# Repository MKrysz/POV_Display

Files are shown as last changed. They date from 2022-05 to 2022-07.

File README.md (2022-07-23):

# Persistance Of Vision Display

## About

Human eye cannot process more than 12 images per second. So by turning on and off moving LEDs it is possible to create an illusion of a stationary image. The goal of this project is to develop a display utilizing this principle. Main modes of the display are going to be: analog and digital clock, showing images and playing videos.

hello world (https://www.youtube.com/watch?v=nO5H2S38heM)
analog clock (https://www.youtube.com/watch?v=prxCtZcyvlo)

## Electronics

As the main purpose of this display is to have a fancy wall clock, one of the main concerns in electronics design was power usage. That's why I decided to use STM32L051C8 as the main MCU, due to its low power usage, high computational capabilities and my familiarity with STM's HAL interface. Power supply consists of Li-Po battery and 2.5V low dropout voltage regulator. Charging battery is done via micro-USB port with TP4056 IC. For driving LEDs I chose a combination of classical 74HC595 8-bit SIPO registers and current limiting resistors. Photodiode is used for calculating rotation time.

Using the KiCad software I came up with following schematic:
Schematic

And PCB design:
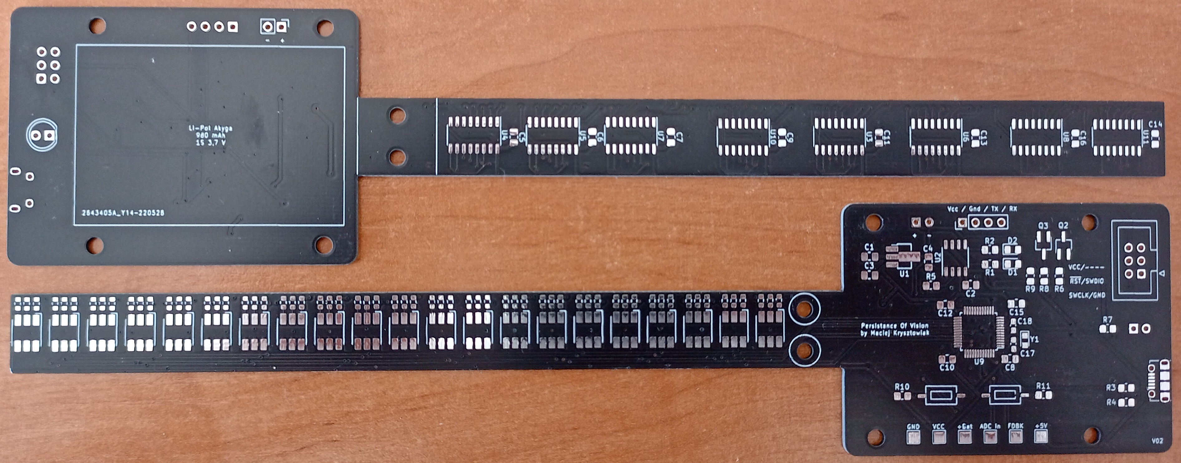
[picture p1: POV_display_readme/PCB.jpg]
PCB


Board after assembling:
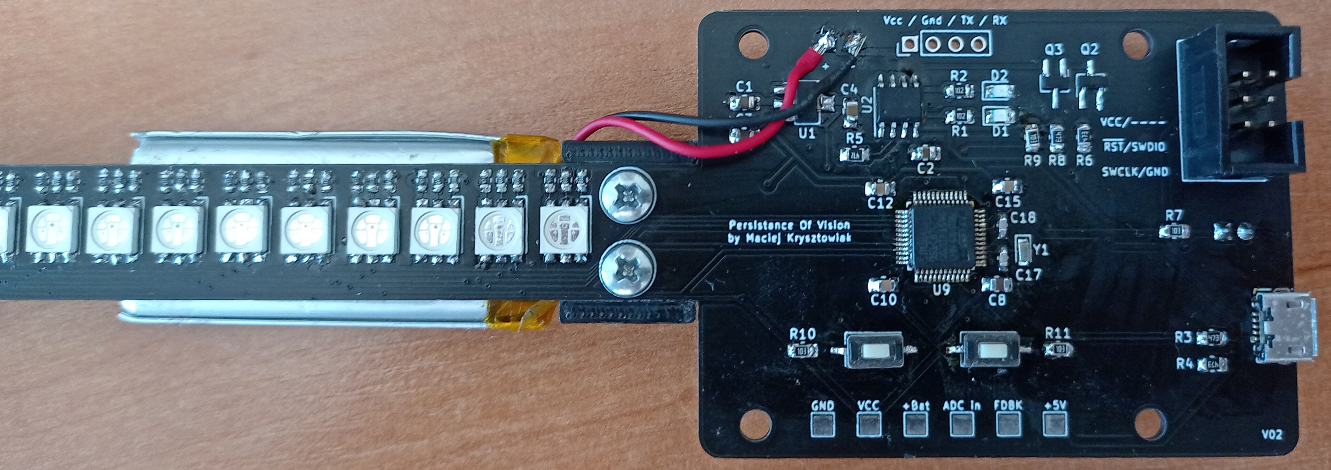
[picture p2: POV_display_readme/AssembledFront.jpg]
Assembled Front

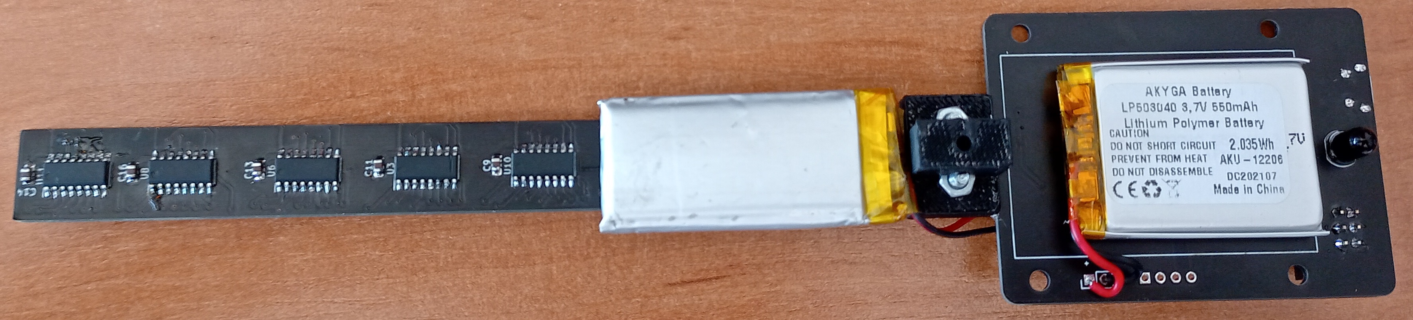
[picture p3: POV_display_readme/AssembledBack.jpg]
Assembled Back


After I glued the main battery in the board wasn't balanced and after trying few methods, I stuck with adding 2nd battery for increased battery life in addition to balancing the PCB.

## MECHANICS

Rotor holder used for connecting the PCB to rotor using two pairs of M3 nuts and bolts.
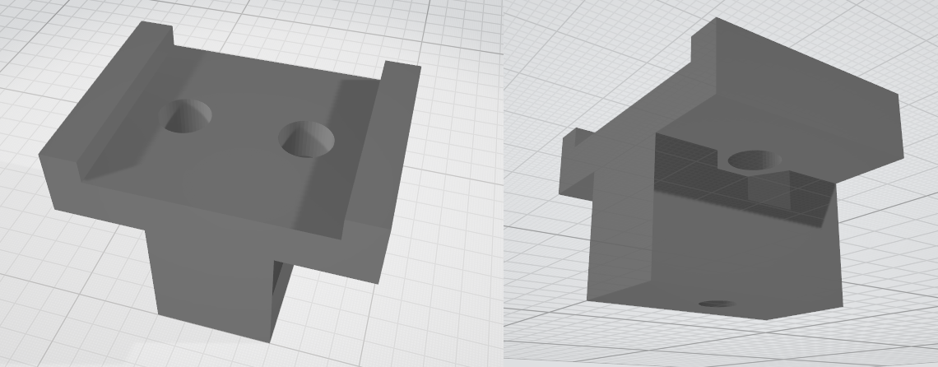
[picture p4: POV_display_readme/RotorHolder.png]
Rotor holder


Motor hodler was printed in 3 separate part because my 3D printer was too small. Parts are mounted together using M3 and M4 nuts and bolts. Motor holder also embeds IR LED.
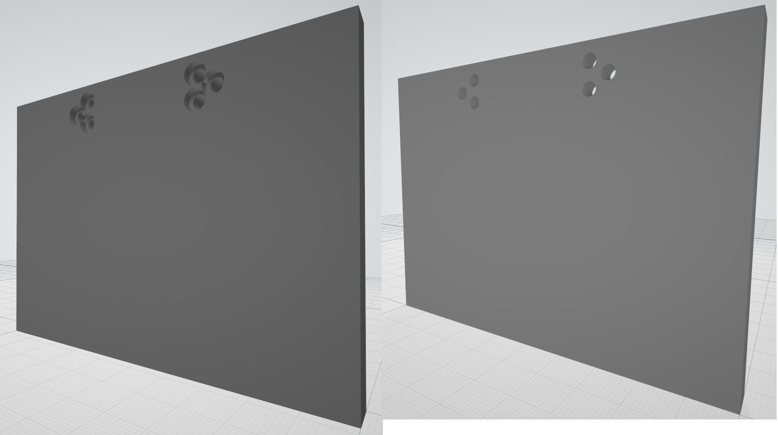
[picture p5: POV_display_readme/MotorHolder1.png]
Motor holder part1

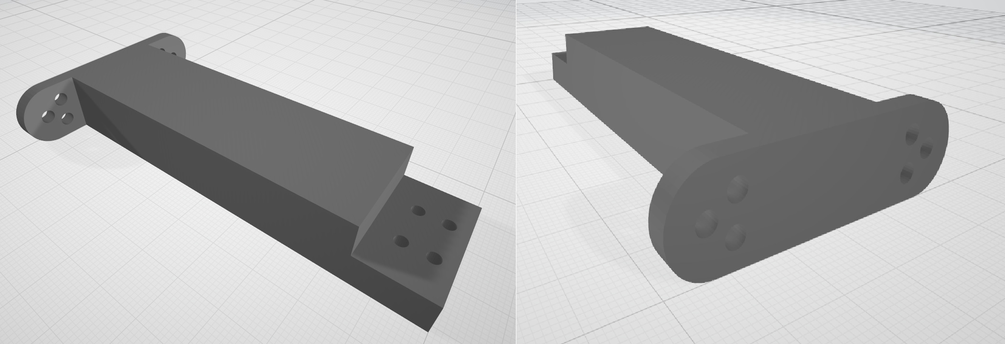
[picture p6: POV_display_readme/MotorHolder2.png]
Motor holder part2

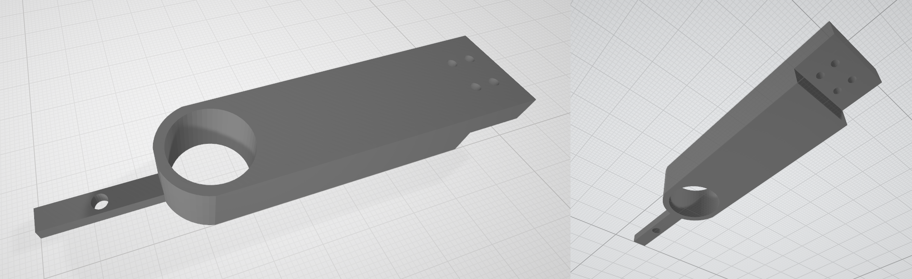
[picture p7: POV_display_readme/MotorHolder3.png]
Motor holder part3


All parts were printed with ABS material.

## SOFTWARE

### IMAGE COMPILER

Python script used for coverting images into a C-style array, that could be programmed into the MCU.

### Embedded

Project was made in VSCode using [stm32-for-vscode](https://www.st.com/en/development-tools/stm32cubemx.html) extension. For this project I used [stm32CubeMX](https://github.com/bmd-studio/stm32-for-vscode) for generating initialization. There are 2 main modes that the display can work in:

- Analog Clock - Mimics classical analog clock
- Image - Displays stationary images, precompiled with python script

Modes and parameters can be chosen via *config.h* file.

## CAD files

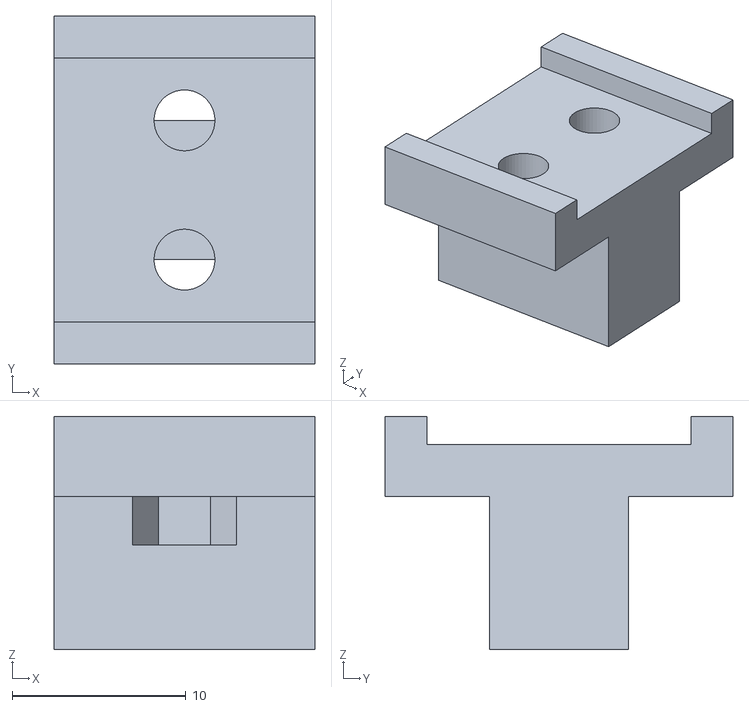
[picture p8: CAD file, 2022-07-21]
POV_display_models/RotorHolder.stl
15.0 x 20.0 x 13.4

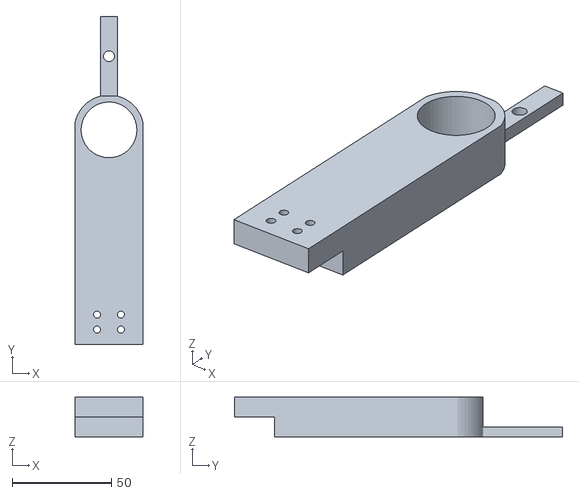
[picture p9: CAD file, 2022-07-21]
POV_display_models/MotorHolder3.stl
34.0 x 164.9 x 20.0

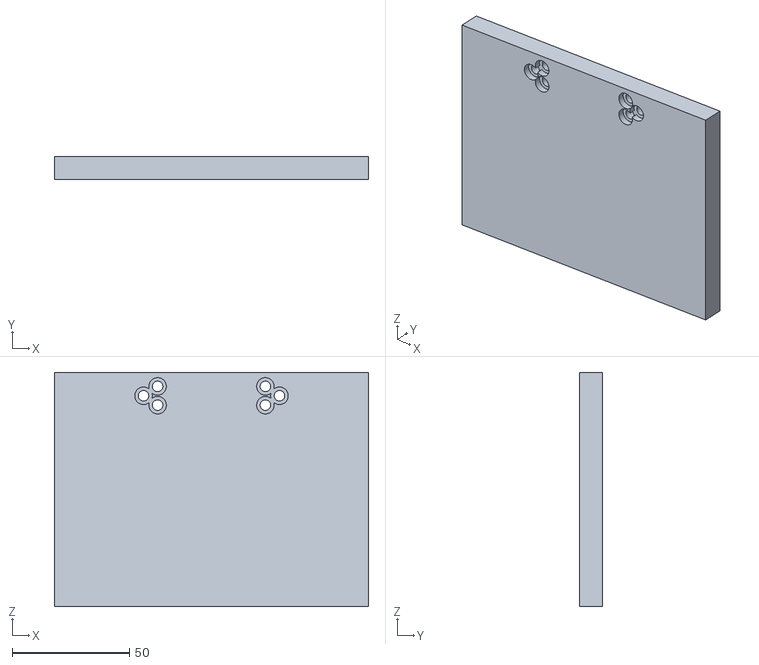
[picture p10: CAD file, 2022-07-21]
POV_display_models/MotorHolder1.stl
134.0 x 10.0 x 100.0

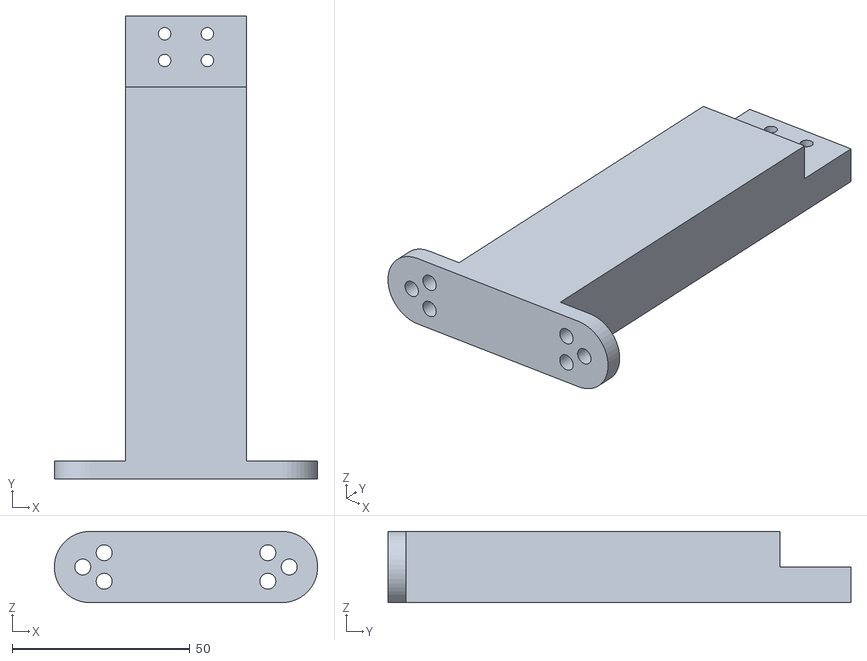
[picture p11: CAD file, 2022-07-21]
POV_display_models/MotorHolder2.stl
74.0 x 130.1 x 20.0

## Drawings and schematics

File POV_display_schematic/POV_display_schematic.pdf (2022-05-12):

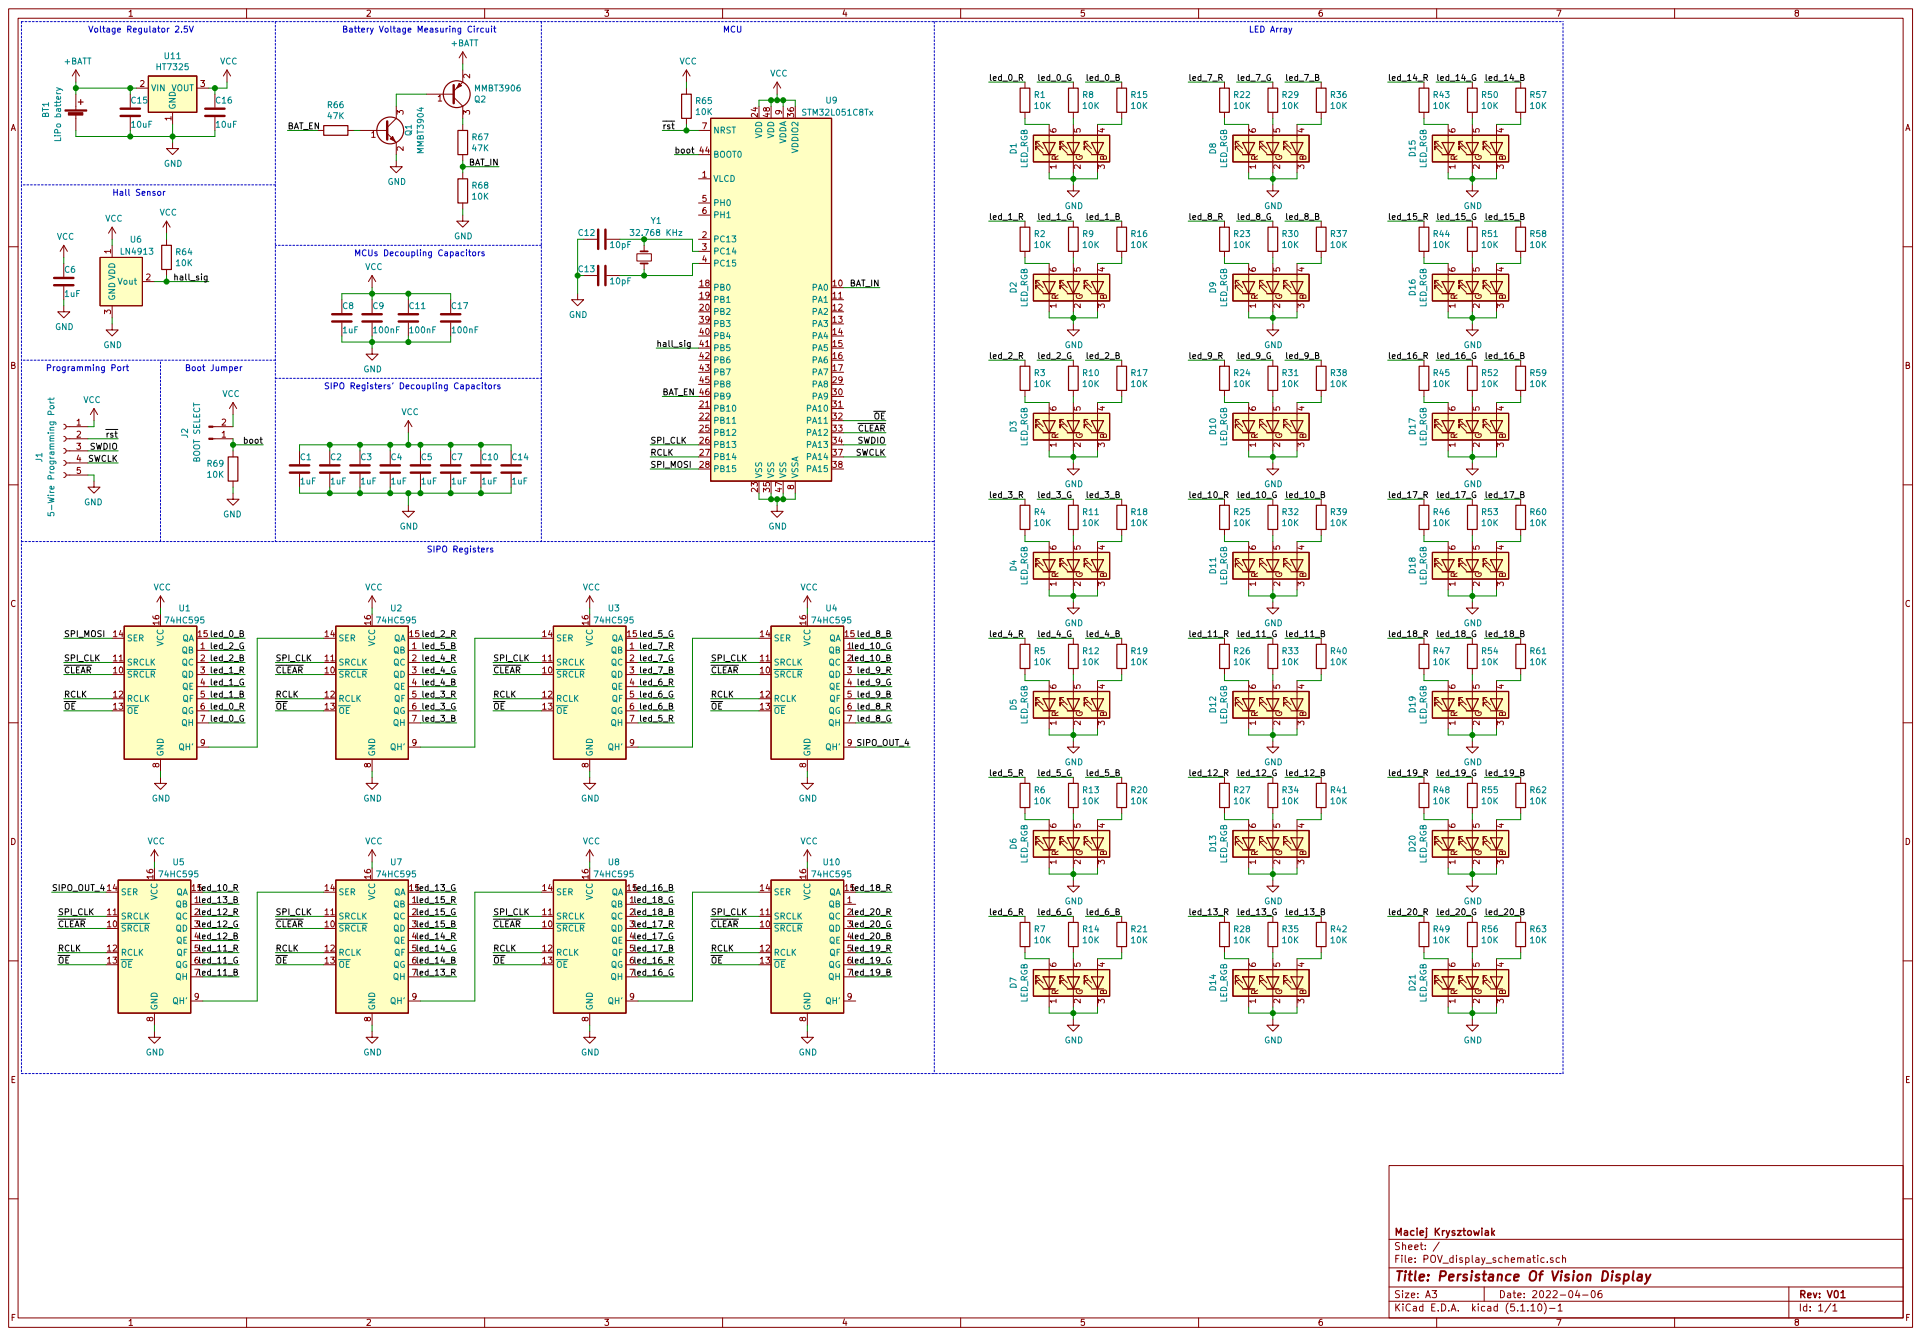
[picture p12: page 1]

4 D1 LED_RGB BT1 LiPo battery GND GND

9 VDDIO2 36 VLCD 1 VSS 23 VSS 35 VSS 47 VSSA

SIPO Registers' Decoupling Capacitors

led_12_R | led_15_G
led_12_G | led_15_B

led_11_R | led_14_G
led_11_G | led_14_B

File: POV_display_schematic.sch Sheet: / Maciej Krysztowiak

Id: 1/1 Title: Persistance Of Vision Display

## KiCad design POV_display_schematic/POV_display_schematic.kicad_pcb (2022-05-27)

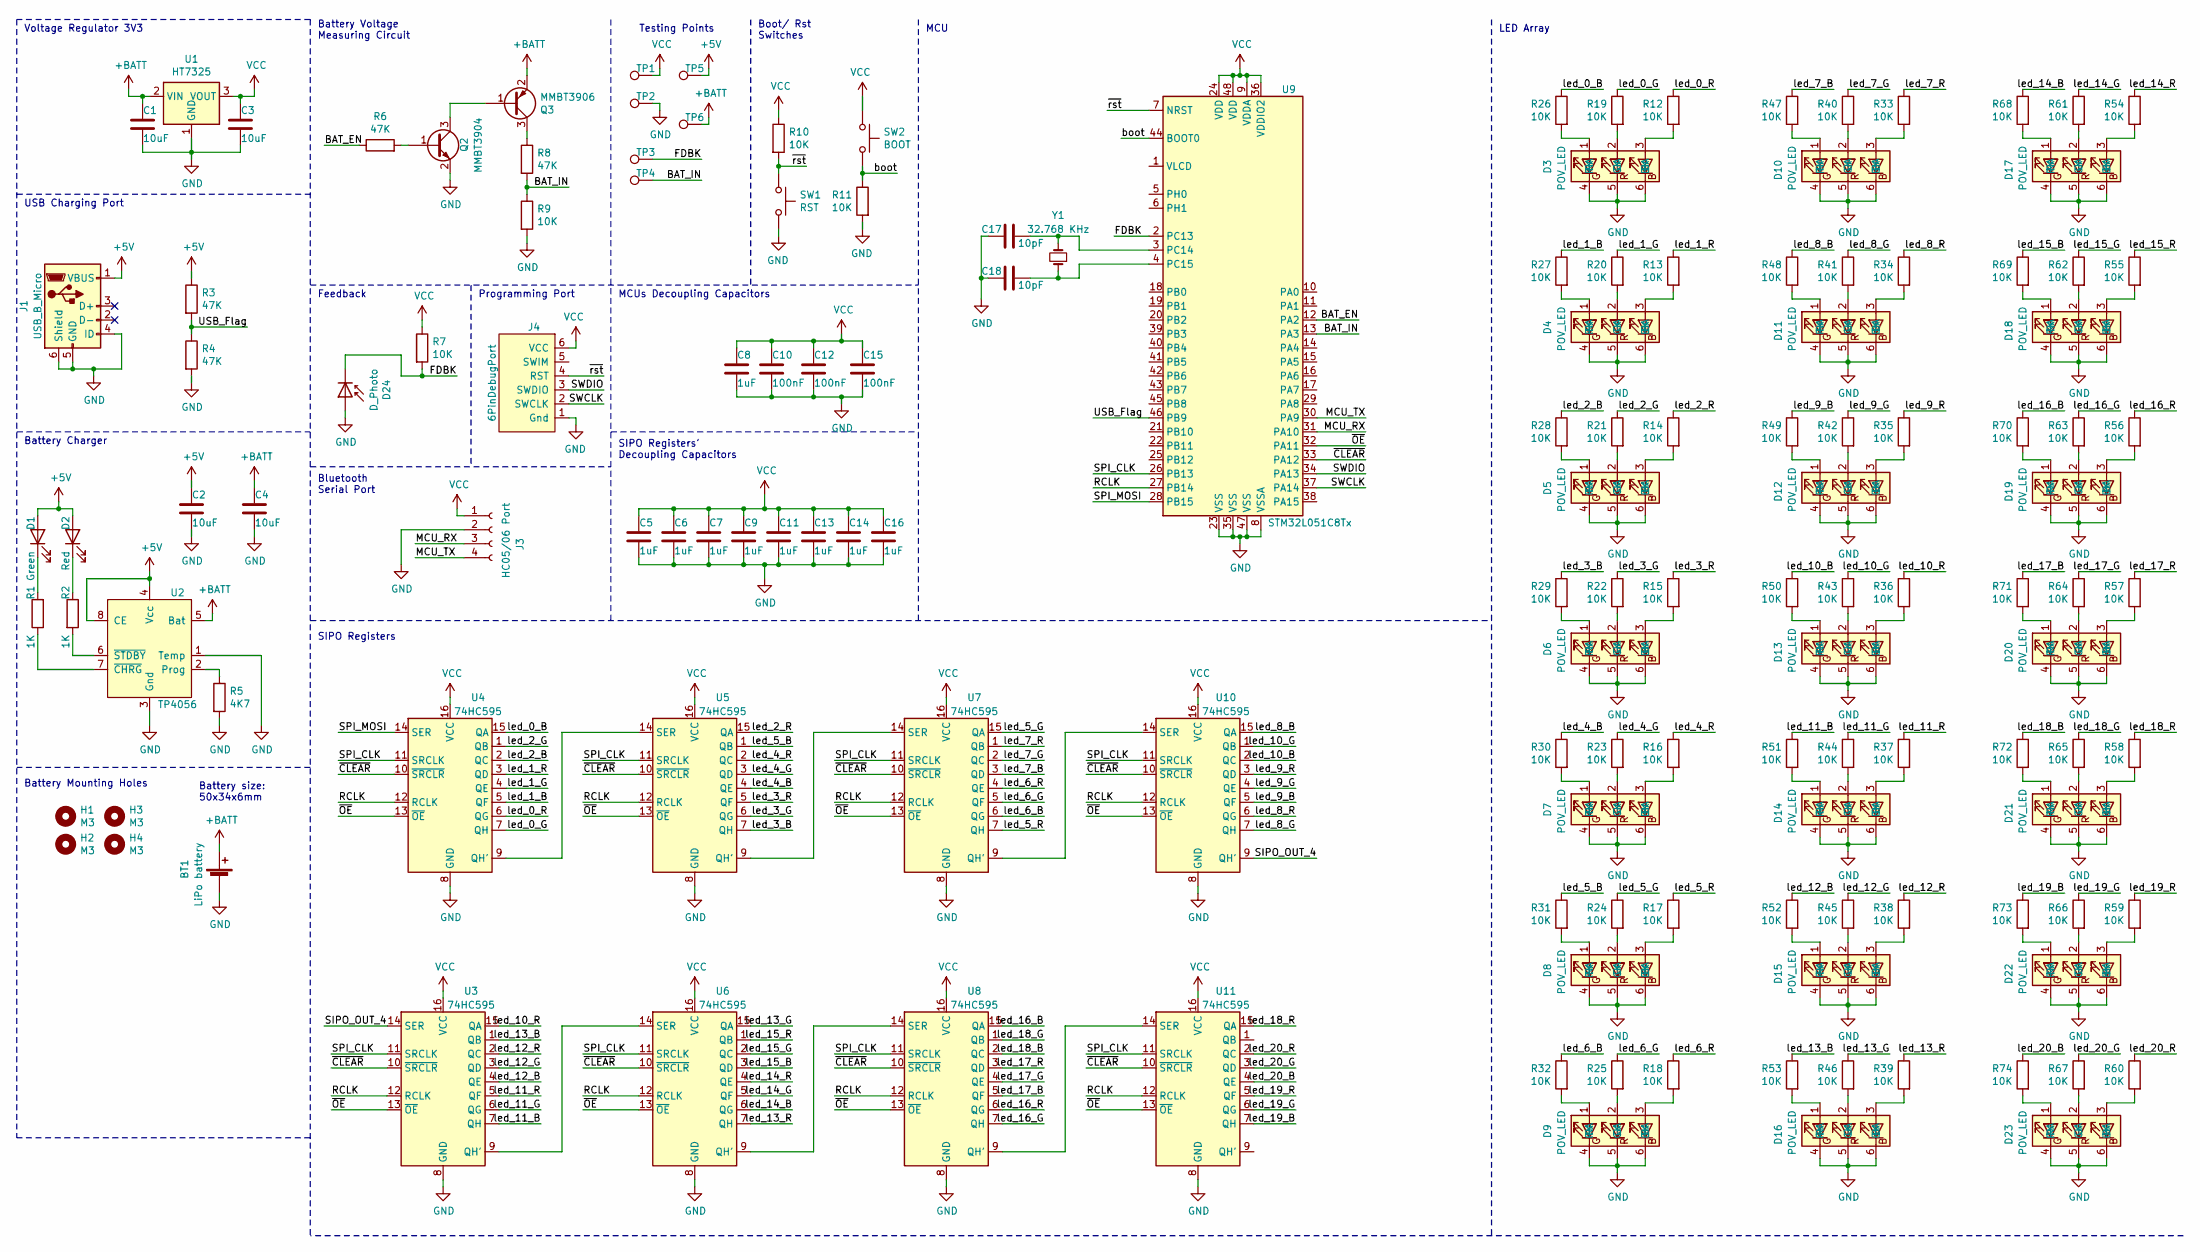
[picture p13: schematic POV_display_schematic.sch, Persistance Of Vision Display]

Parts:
BT1: LiPo battery; PinHeader_1x02_P2.54mm_Vertical
C1, C2, C3, C4: 10uF; C_0805_2012Metric_Pad1.18x1.45mm_HandSolder
C5, C6, C7, C8, C9, C11, C13, C14, C16: 1uF; C_0805_2012Metric_Pad1.18x1.45mm_HandSolder
C10, C12, C15: 100nF; C_0805_2012Metric_Pad1.18x1.45mm_HandSolder
C17, C18: 10pF; C_0603_1608Metric_Pad1.08x0.95mm_HandSolder
D1: Green; LED_0805_2012Metric_Pad1.15x1.40mm_HandSolder
D2: Red; LED_0805_2012Metric_Pad1.15x1.40mm_HandSolder
D3, D4, D5, D6, D7, D8, D9, D10, D11, D12, D13, D14, D15, D16, D17, D18, D19, D20, D21, D22, D23: POV_LED; LED_RGB_5050-6
D24: D_Photo; LED_D5.0mm
H1, H2, H3, H4: M3; MountingHole_3.2mm_M3
J1: USB_B_Micro; USB_Micro-B_Molex-105017-0001
J3: HC05/06 Port; PinHeader_1x04_P2.54mm_Vertical
J4: 6PinDebugPort; IDC-Header_2x03_P2.54mm_Vertical
Q2: MMBT3904; TSOT-23_HandSoldering
Q3: MMBT3906; TSOT-23_HandSoldering
R1, R2: 1K; R_0805_2012Metric_Pad1.20x1.40mm_HandSolder
R3, R4, R6, R8: 47K; R_0805_2012Metric_Pad1.20x1.40mm_HandSolder
R5: 4K7; R_0805_2012Metric_Pad1.20x1.40mm_HandSolder
R7, R9, R10, R11: 10K; R_0805_2012Metric_Pad1.20x1.40mm_HandSolder
R12, R13, R14, R15, R16, R17, R18, R19, R20, R21, R22, R23, R24, R25, R26, R27, R28, R29, R30, R31, R32, R33, R34, R35, R36, R37, R38, R39, R40, R41, R42, R43, R44, R45, R46, R47, R48, R49, R50, R51, R52, R53, R54, R55, R56, R57, R58, R59, R60, R61, R62, R63, R64, R65, R66, R67, R68, R69, R70, R71, R72, R73, R74: 10K; R_0603_1608Metric
SW1: RST; TSB008
SW2: BOOT; TSB008
TP1, TP2, TP3, TP4, TP5, TP6: TestPoint; TestPoint_Pad_2.0x2.0mm
U1: HT7325; SOT-89-3_Handsoldering
U2: TP4056; SOP-8_3.9x4.9mm_P1.27mm
U3, U4, U5, U6, U7, U8, U10, U11: 74HC595; SO-16_3.9x9.9mm_P1.27mm
U9: STM32L051C8Tx; LQFP-48_7x7mm_P0.5mm
Y1: 32.768 KHz; Crystal_SMD_2012-2Pin_2.0x1.2mm_HandSoldering

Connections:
+5V: C2.1, D1.2 (A), D2.2 (A), J1.1 (VBUS), R3.1, TP5.1, U2.4 (Vcc), U2.8 (CE)
+BATT: BT1.1 (+), C1.1, C4.1, Q3.2 (E), TP6.1, U1.2 (VIN), U2.5 (Bat)
/BAT_EN: R6.1, U9.12 (PA2)
/BAT_IN: R8.2, R9.1, TP4.1, U9.13 (PA3)
/FDBK: D24.1 (K), R7.2, TP3.1, U9.2 (PC13)
/MCU_RX: J3.3, U9.31 (PA10)
/MCU_TX: J3.4, U9.30 (PA9)
/RCLK: U3.12 (RCLK), U4.12 (RCLK), U5.12 (RCLK), U6.12 (RCLK), U7.12 (RCLK), U8.12 (RCLK), U9.27 (PB14), U10.12 (RCLK), U11.12 (RCLK)
/SIPO_OUT_4: U3.14 (SER), U10.9 (QH')
/SPI_CLK: U3.11 (SRCLK), U4.11 (SRCLK), U5.11 (SRCLK), U6.11 (SRCLK), U7.11 (SRCLK), U8.11 (SRCLK), U9.26 (PB13), U10.11 (SRCLK), U11.11 (SRCLK)
/SPI_MOSI: U4.14 (SER), U9.28 (PB15)
/SWCLK: J4.2 (SWCLK), U9.37 (PA14)
/SWDIO: J4.3 (SWDIO), U9.34 (PA13)
/USB_Flag: R3.2, R4.1, U9.46 (PB9)
/boot: R11.1, SW2.2, U9.44 (BOOT0)
/led_0_B: R26.1, U4.15 (QA)
/led_0_G: R19.1, U4.7 (QH)
/led_0_R: R12.1, U4.6 (QG)
/led_1_B: R27.1, U4.5 (QF)
/led_1_G: R20.1, U4.4 (QE)
/led_1_R: R13.1, U4.3 (QD)
/led_2_B: R28.1, U4.2 (QC)
/led_2_G: R21.1, U4.1 (QB)
/led_2_R: R14.1, U5.15 (QA)
/led_3_B: R29.1, U5.7 (QH)
/led_3_G: R22.1, U5.6 (QG)
/led_3_R: R15.1, U5.5 (QF)
/led_4_B: R30.1, U5.4 (QE)
/led_4_G: R23.1, U5.3 (QD)
/led_4_R: R16.1, U5.2 (QC)
/led_5_B: R31.1, U5.1 (QB)
/led_5_G: R24.1, U7.15 (QA)
/led_5_R: R17.1, U7.7 (QH)
/led_6_B: R32.1, U7.6 (QG)
/led_6_G: R25.1, U7.5 (QF)
/led_6_R: R18.1, U7.4 (QE)
/led_7_B: R47.1, U7.3 (QD)
/led_7_G: R40.1, U7.2 (QC)
/led_7_R: R33.1, U7.1 (QB)
/led_8_B: R48.1, U10.15 (QA)
/led_8_G: R41.1, U10.7 (QH)
/led_8_R: R34.1, U10.6 (QG)
/led_9_B: R49.1, U10.5 (QF)
/led_9_G: R42.1, U10.4 (QE)
/led_9_R: R35.1, U10.3 (QD)
/led_10_B: R50.1, U10.2 (QC)
/led_10_G: R43.1, U10.1 (QB)
/led_10_R: R36.1, U3.15 (QA)
/led_11_B: R51.1, U3.7 (QH)
/led_11_G: R44.1, U3.6 (QG)
/led_11_R: R37.1, U3.5 (QF)
/led_12_B: R52.1, U3.4 (QE)
/led_12_G: R45.1, U3.3 (QD)
/led_12_R: R38.1, U3.2 (QC)
/led_13_B: R53.1, U3.1 (QB)
/led_13_G: R46.1, U6.15 (QA)
/led_13_R: R39.1, U6.7 (QH)
/led_14_B: R68.1, U6.6 (QG)
/led_14_G: R61.1, U6.5 (QF)
/led_14_R: R54.1, U6.4 (QE)
/led_15_B: R69.1, U6.3 (QD)
/led_15_G: R62.1, U6.2 (QC)
/led_15_R: R55.1, U6.1 (QB)
/led_16_B: R70.1, U8.15 (QA)
/led_16_G: R63.1, U8.7 (QH)
/led_16_R: R56.1, U8.6 (QG)
/led_17_B: R71.1, U8.5 (QF)
/led_17_G: R64.1, U8.4 (QE)
/led_17_R: R57.1, U8.3 (QD)
/led_18_B: R72.1, U8.2 (QC)
/led_18_G: R65.1, U8.1 (QB)
/led_18_R: R58.1, U11.15 (QA)
/led_19_B: R73.1, U11.7 (QH)
/led_19_G: R66.1, U11.6 (QG)
/led_19_R: R59.1, U11.5 (QF)
/led_20_B: R74.1, U11.4 (QE)
/led_20_G: R67.1, U11.3 (QD)
/led_20_R: R60.1, U11.2 (QC)
/~CLEAR: U3.10 (~SRCLR), U4.10 (~SRCLR), U5.10 (~SRCLR), U6.10 (~SRCLR), U7.10 (~SRCLR), U8.10 (~SRCLR), U9.33 (PA12), U10.10 (~SRCLR), U11.10 (~SRCLR)
/~OE: U3.13 (~OE), U4.13 (~OE), U5.13 (~OE), U6.13 (~OE), U7.13 (~OE), U8.13 (~OE), U9.32 (PA11), U10.13 (~OE), U11.13 (~OE)
/~rst: J4.4 (RST), R10.2, SW1.1, U9.7 (NRST)
GND: BT1.2 (-), C1.2, C2.2, C3.2, C4.2, C5.2, C6.2, C7.2, C8.2, C9.2, C10.2, C11.2, C12.2, C13.2, C14.2, C15.2, C16.2, C17.1, C18.1, D3.4 (RK), D3.5 (GK), D3.6 (BK), D4.4 (RK), D4.5 (GK), D4.6 (BK), D5.4 (RK), D5.5 (GK), D5.6 (BK), D6.4 (RK), D6.5 (GK), D6.6 (BK), D7.4 (RK), D7.5 (GK), D7.6 (BK), D8.4 (RK), D8.5 (GK), D8.6 (BK), D9.4 (RK), D9.5 (GK), D9.6 (BK), D10.4 (RK), D10.5 (GK), D10.6 (BK), D11.4 (RK), D11.5 (GK), D11.6 (BK), D12.4 (RK), D12.5 (GK), D12.6 (BK), D13.4 (RK), D13.5 (GK), D13.6 (BK), D14.4 (RK), D14.5 (GK), D14.6 (BK), D15.4 (RK), D15.5 (GK), D15.6 (BK), D16.4 (RK), D16.5 (GK), D16.6 (BK), D17.4 (RK), D17.5 (GK), D17.6 (BK), D18.4 (RK), D18.5 (GK), D18.6 (BK), D19.4 (RK), D19.5 (GK), D19.6 (BK), D20.4 (RK), D20.5 (GK), D20.6 (BK), D21.4 (RK), D21.5 (GK), D21.6 (BK), D22.4 (RK), D22.5 (GK), D22.6 (BK), D23.4 (RK), D23.5 (GK), D23.6 (BK), D24.2 (A), J1.4 (ID), J1.5 (GND), J1.6 (Shield), J3.2, J4.1 (Gnd), Q2.2 (E), R4.2, R5.2, R9.2, R11.2, SW1.2, TP2.1, U1.1 (GND), U2.1 (Temp), U2.3 (Gnd), U3.8 (GND), U4.8 (GND), U5.8 (GND), U6.8 (GND), U7.8 (GND), U8.8 (GND), U9.8 (VSSA), U9.23 (VSS), U9.35 (VSS), U9.47 (VSS), U10.8 (GND), U11.8 (GND)
unnamed: C17.2, U9.3 (PC14), Y1.2
unnamed: C18.2, U9.4 (PC15), Y1.1
unnamed: D1.1 (K), R1.2
unnamed: D2.1 (K), R2.1
unnamed: D3.1 (RA), R26.2
unnamed: D3.2 (GA), R19.2
unnamed: D3.3 (BA), R12.2
unnamed: D4.1 (RA), R27.2
unnamed: D4.2 (GA), R20.2
unnamed: D4.3 (BA), R13.2
unnamed: D5.1 (RA), R28.2
unnamed: D5.2 (GA), R21.2
unnamed: D5.3 (BA), R14.2
unnamed: D6.1 (RA), R29.2
unnamed: D6.2 (GA), R22.2
unnamed: D6.3 (BA), R15.2
unnamed: D7.1 (RA), R30.2
unnamed: D7.2 (GA), R23.2
unnamed: D7.3 (BA), R16.2
unnamed: D8.1 (RA), R31.2
unnamed: D8.2 (GA), R24.2
unnamed: D8.3 (BA), R17.2
unnamed: D9.1 (RA), R32.2
unnamed: D9.2 (GA), R25.2
unnamed: D9.3 (BA), R18.2
unnamed: D10.1 (RA), R47.2
unnamed: D10.2 (GA), R40.2
unnamed: D10.3 (BA), R33.2
unnamed: D11.1 (RA), R48.2
unnamed: D11.2 (GA), R41.2
unnamed: D11.3 (BA), R34.2
unnamed: D12.1 (RA), R49.2
unnamed: D12.2 (GA), R42.2
unnamed: D12.3 (BA), R35.2
unnamed: D13.1 (RA), R50.2
unnamed: D13.2 (GA), R43.2
unnamed: D13.3 (BA), R36.2
unnamed: D14.1 (RA), R51.2
unnamed: D14.2 (GA), R44.2
unnamed: D14.3 (BA), R37.2
unnamed: D15.1 (RA), R52.2
unnamed: D15.2 (GA), R45.2
unnamed: D15.3 (BA), R38.2
unnamed: D16.1 (RA), R53.2
unnamed: D16.2 (GA), R46.2
unnamed: D16.3 (BA), R39.2
unnamed: D17.1 (RA), R68.2
unnamed: D17.2 (GA), R61.2
unnamed: D17.3 (BA), R54.2
unnamed: D18.1 (RA), R69.2
unnamed: D18.2 (GA), R62.2
unnamed: D18.3 (BA), R55.2
unnamed: D19.1 (RA), R70.2
unnamed: D19.2 (GA), R63.2
unnamed: D19.3 (BA), R56.2
unnamed: D20.1 (RA), R71.2
unnamed: D20.2 (GA), R64.2
unnamed: D20.3 (BA), R57.2
unnamed: D21.1 (RA), R72.2
unnamed: D21.2 (GA), R65.2
unnamed: D21.3 (BA), R58.2
unnamed: D22.1 (RA), R73.2
unnamed: D22.2 (GA), R66.2
unnamed: D22.3 (BA), R59.2
unnamed: D23.1 (RA), R74.2
unnamed: D23.2 (GA), R67.2
unnamed: D23.3 (BA), R60.2
unnamed: Q2.1 (B), R6.2
unnamed: Q2.3 (C), Q3.1 (B)
unnamed: Q3.3 (C), R8.1
unnamed: R1.1, U2.7 (~CHRG)
unnamed: R2.2, U2.6 (~STDBY)
unnamed: R5.1, U2.2 (Prog)
unnamed: U3.9 (QH'), U6.14 (SER)
unnamed: U4.9 (QH'), U5.14 (SER)
unnamed: U5.9 (QH'), U7.14 (SER)
unnamed: U6.9 (QH'), U8.14 (SER)
unnamed: U7.9 (QH'), U10.14 (SER)
unnamed: U8.9 (QH'), U11.14 (SER)
VCC: C3.1, C5.1, C6.1, C7.1, C8.1, C9.1, C10.1, C11.1, C12.1, C13.1, C14.1, C15.1, C16.1, J3.1, J4.6 (VCC), R7.1, R10.1, SW2.1, TP1.1, U1.3 (VOUT), U3.16 (VCC), U4.16 (VCC), U5.16 (VCC), U6.16 (VCC), U7.16 (VCC), U8.16 (VCC), U9.9 (VDDA), U9.24 (VDD), U9.36 (VDDIO2), U9.48 (VDD), U10.16 (VCC), U11.16 (VCC)

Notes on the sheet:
Voltage Regulator 3V3
Battery Voltage Measuring Circuit
MCU
MCUs Decoupling Capacitors
Feedback
Programming Port
Boot/ Rst Switches
LED Array
USB Charging Port
SIPO Registers' Decoupling Capacitors
SIPO Registers
Battery Charger
Battery Mounting Holes
Testing Points
Bluetooth Serial Port
Battery size: 50x34x6mm

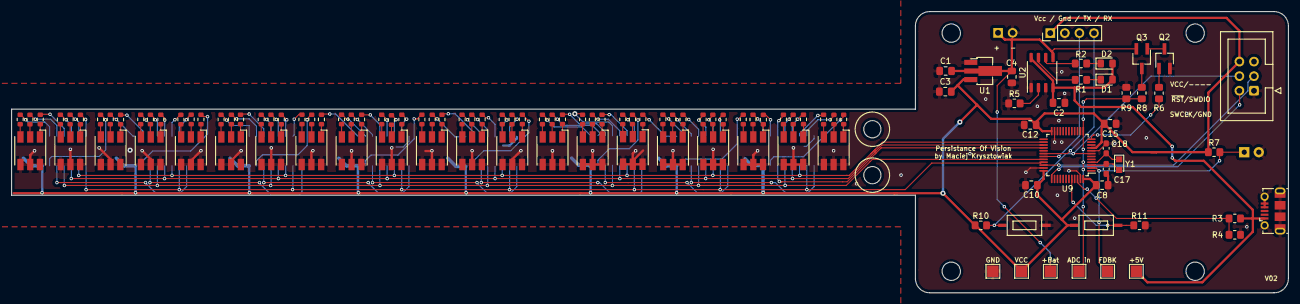
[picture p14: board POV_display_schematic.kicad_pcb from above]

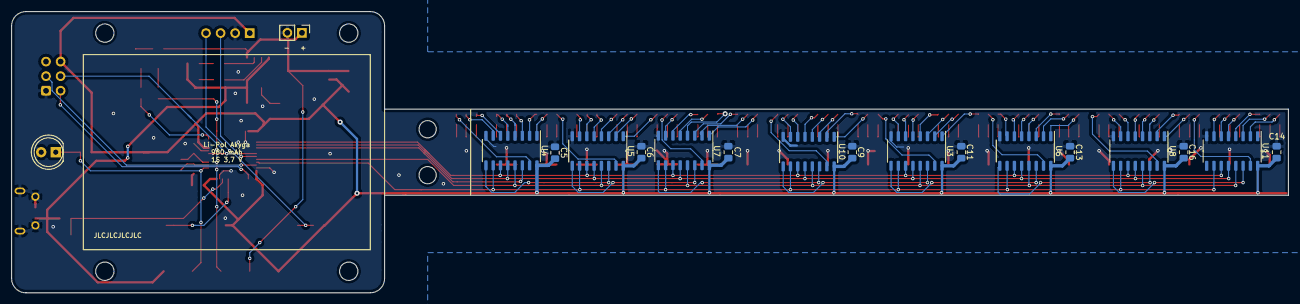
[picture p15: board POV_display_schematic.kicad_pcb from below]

Board: 2 copper layers, 222.5 x 49.0 mm, 146 parts (18 on the bottom side), 162 nets.

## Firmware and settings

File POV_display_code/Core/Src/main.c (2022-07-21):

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
/* Includes ------------------------------------------------------------------*/
#include "main.h"
#include "adc.h"
#include "dma.h"
#include "rtc.h"
#include "spi.h"
#include "tim.h"
#include "usart.h"
#include "gpio.h"

/* USER CODE BEGIN Includes */
#include "led.h"
#include "clk.h"
#include "img.h"
#include "array.h"
#include <stdbool.h>
#include "config.h"
/* USER CODE END Includes */


/* USER CODE BEGIN PV */
/**
 * @brief time of full rotation in ms
 * 
 */
volatile uint16_t period = 0;

/**
 * @brief time of full rotation in us
 * 
 */
volatile uint16_t periodUS = 0;

extern volatile bool GPIO_Flag;
volatile size_t imgIdx = 0;
volatile bool isShutDown = false;

/* USER CODE END PV */

void SystemClock_Config(void);
/**
  * @brief  The application entry point.
  * @retval int
  */
int main(void)
{
  /* MCU Configuration--------------------------------------------------------*/

  /* Reset of all peripherals, Initializes the Flash interface and the Systick. */
  HAL_Init();

  /* Configure the system clock */
  SystemClock_Config();

  /* Initialize all configured peripherals */
  MX_GPIO_Init();
  MX_ADC_Init();
  MX_SPI2_Init();
  MX_RTC_Init();
  MX_DMA_Init();
  MX_TIM2_Init();
  MX_USART1_UART_Init();
  /* USER CODE BEGIN 2 */
  TIM_Init();
  GPIO_Init();
  LED_Init();
  LED_AllBlack();
  HAL_Delay(1500);
  LED_AllWhite();
  // while(1);
  HAL_Delay(1500);
  LED_AllBlack();
  
  uint16_t prev_millis = 0;
  #ifdef MODE_IMAGE
    const size_t imgIdxMax = IMG_SIZE;
    for (size_t i = 0; i < imgIdxMax; i++)
    {
      LED_Send(image[i]);
      HAL_Delay(2000/imgIdxMax);
    }
    
  #endif
  #ifdef MODE_ANALOG_CLOCK
    const size_t imgIdxMax = 120;
  #endif
  /* USER CODE END 2 */

  /* Infinite loop */
  /* USER CODE BEGIN WHILE */

  /**
   * @brief time in ms since last full rotation after which display goes dormant
   * 
   */
  const uint16_t shutdownTime = 500;

  while (1)
  {
    #if SHUTDOWN_ENABLE
    if(imgIdx > 3*imgIdxMax){
      sleepRoutine();
    }
    #endif

    #ifdef MODE_IMAGE

    // LED_Send(image[(imgIdx+imgIdxMax*3/4)%imgIdxMax]);
    LED_Send(image[(imgIdx)%imgIdxMax]);

    #endif


    #ifdef MODE_ANALOG_CLOCK
    uint8_t sendData[8];
    // size_t tempIdx = imgIdx;         
    size_t tempIdx = (imgIdx + 3 + imgIdxMax/2) % imgIdxMax;

    //add background
    ARRAY_Copy(CLK_BKGD[tempIdx], sendData, 8);

    // //add hands
    RTC_TimeTypeDef currentTime; 
    RTC_DateTypeDef currentDate; 
    HAL_RTC_GetTime(&hrtc, &currentTime, RTC_FORMAT_BIN);
    HAL_RTC_GetDate(&hrtc, &currentDate, RTC_FORMAT_BIN);

    if(currentTime.Hours * 10 == tempIdx)
      ARRAY_BitwiseOR(sendData, hours, sendData, 8);
    if(currentTime.Minutes * 2 == tempIdx)
      ARRAY_BitwiseOR(sendData, minutes, sendData, 8);
    if(currentTime.Seconds * 2 == tempIdx)
      ARRAY_BitwiseOR(sendData, seconds, sendData, 8);

    LED_Send(sendData);

    #endif

    //progress in showing img
    imgIdx++;

    //delay routine
    while(true){
      //us delay from us period
      // if(__HAL_TIM_GET_COUNTER(&HTIM_US_GET) - prev_millis >= (uint16_t)(periodUS/(imgIdxMax+1)))
      if(__HAL_TIM_GET_COUNTER(&HTIM_US_GET) - prev_millis >= (uint16_t)(periodUS/(imgIdxMax)))
        break;
      if(GPIO_Flag){
        //if anchor point detected stop waiting and show another column
        GPIO_Flag = false;
        break;
      }
    }
    prev_millis = __HAL_TIM_GET_COUNTER(&HTIM_US_GET);
    /* USER CODE END WHILE */

    /* USER CODE BEGIN 3 */
  }
  /* USER CODE END 3 */
}

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
/* USER CODE BEGIN 4 */
void sleepRoutine()
{
  LED_AllBlack();
  periodUS = 0;
  isShutDown = true;
  
  HAL_SuspendTick();
  HAL_PWR_EnterSTOPMode(PWR_LOWPOWERREGULATOR_ON, PWR_STOPENTRY_WFI);
}


void wakeUpRoutine()
{
  isShutDown = false;
  SystemClock_Config();
  HAL_ResumeTick();
}

/* USER CODE END 4 */
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


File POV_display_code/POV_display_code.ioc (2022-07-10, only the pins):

Mcu.UserName=STM32L051C8Tx
PA10.Signal=USART1_RX
PA11.GPIO_Label=NOT_OE
PA11.Signal=GPIO_Output
PA12.GPIO_Label=NOT_CLEAR
PA12.Signal=GPIO_Output
PA13.Signal=SYS_SWDIO
PA14.Signal=SYS_SWCLK
PA2.GPIO_Label=BAT_EN
PA2.Signal=GPIO_Output
PA3.GPIO_Label=BAT_IN
PA3.Signal=ADC_IN3
PA9.Signal=USART1_TX
PB13.Signal=SPI2_SCK
PB14.GPIO_Label=RCLK
PB14.Signal=GPIO_Output
PB15.Signal=SPI2_MOSI
PB9.GPIO_Label=USB_FLAG
PB9.Signal=GPIO_Input
PC13.GPIO_Label=FDBK
PC13.Signal=GPXTI13
PC14-OSC32_IN.Signal=RCC_OSC32_IN
PC15-OSC32_OUT.Signal=RCC_OSC32_OUT

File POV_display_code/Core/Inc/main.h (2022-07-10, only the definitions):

#define FDBK_Pin GPIO_PIN_13
#define FDBK_GPIO_Port GPIOC
#define FDBK_EXTI_IRQn EXTI4_15_IRQn
#define BAT_EN_Pin GPIO_PIN_2
#define BAT_EN_GPIO_Port GPIOA
#define BAT_IN_Pin GPIO_PIN_3
#define BAT_IN_GPIO_Port GPIOA
#define RCLK_Pin GPIO_PIN_14
#define RCLK_GPIO_Port GPIOB
#define NOT_OE_Pin GPIO_PIN_11
#define NOT_OE_GPIO_Port GPIOA
#define NOT_CLEAR_Pin GPIO_PIN_12
#define NOT_CLEAR_GPIO_Port GPIOA
#define USB_FLAG_Pin GPIO_PIN_9
#define USB_FLAG_GPIO_Port GPIOB

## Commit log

2022-05-12 Version 01 Upload
    [POV_display_schematic-B_Cu.gbl, POV_display_schematic-B_Mask.gbs, POV_display_schematic-B_Paste.gbp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]
2022-05-12 Uploaded offline work
    [POV_display_schematic.kicad_pcb, POV_display_schematic.sch]
2022-05-19 LEDs footprints are now in correct orientation
    [POV_display_schematic.kicad_pcb, POV_display_schematic.sch]
2022-05-20 Visual changes
    [POV_display_schematic.sch]
2022-05-27 Deleted LEDs' references
    [POV_display_schematic.kicad_pcb]
2022-05-27 Generated Gerbers
    [POV_display_schematic-B_Cu.gbl, POV_display_schematic-B_Mask.gbs, POV_display_schematic-B_Paste.gbp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]
2022-07-10 Minor schematic changes
    [POV_display_schematic.sch]
2022-07-21 Recorded results and updated README
    [MotorHolder1.stl, MotorHolder2.stl, MotorHolder3.stl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]
2022-07-21 Fixed schematic not showing up on README

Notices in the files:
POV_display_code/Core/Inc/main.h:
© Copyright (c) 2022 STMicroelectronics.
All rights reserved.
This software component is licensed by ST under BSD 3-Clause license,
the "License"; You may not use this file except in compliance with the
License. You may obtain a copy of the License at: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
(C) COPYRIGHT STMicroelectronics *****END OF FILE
